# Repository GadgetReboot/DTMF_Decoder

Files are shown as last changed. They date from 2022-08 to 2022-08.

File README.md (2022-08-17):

# DTMF_Decoder
MT8870 DTMF decoder for POTS phone line interfacing <BR>
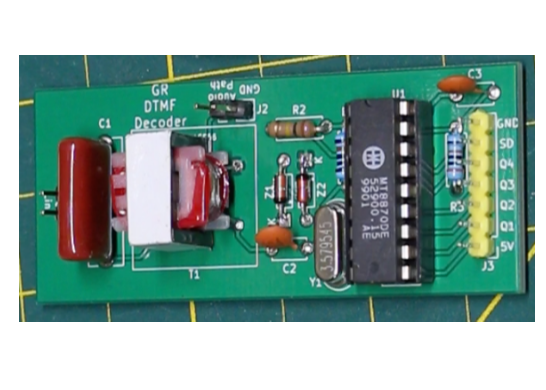
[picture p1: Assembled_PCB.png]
pcb
<br>
This pcb allows connecting across a phone line tip and ring and when DTMF signals are present, they are decoded into 4 bit data with a data ready signal.<br>
An Arduino can then detect DTMF touch tones present on a phone line.<br>
Note: It is recommended to only connect this circuit to a phone line after it is taken off hook to keep the AC voltages low, such as audio signals and not a high voltage ring signal.<br>
This can be achieved by switching the circuit into the phone line with a relay.<br><br>
This circuit has only been tested on a simulated phone line in a workshop environment and is not guaranteed to meet official telephone line specifications.

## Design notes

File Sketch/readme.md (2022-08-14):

DTMF decoder example that prints out the decoded phone key press on the serial monitor

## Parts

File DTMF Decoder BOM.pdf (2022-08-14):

DTMF Decoder BOM

Qty | References | Description
2 | C2 C3 | Capacitor 100nF >=10V 5mm pitch
1 | C1 | Capacitor 0.56uF 250V 15mm pitch
2 | J1 J2 | Header 2.54mm 2 pin
1 | J3 | Header 2.54mm 7 pin
2 | R1 R2 | Resistor 100K 1/4 watt through hole
1 | R3 | Resistor 300K 1/4 watt through hole
1 | T1 | 600:600 Transformer eg. model EI14 on AliExpress
1 | U1 | MT8870DE DIP18
1 | Y1 | 3.579545 MHz HC49/4H
2 | Z1 Z2 | Zener Diode 3V3 1N746A DO-35

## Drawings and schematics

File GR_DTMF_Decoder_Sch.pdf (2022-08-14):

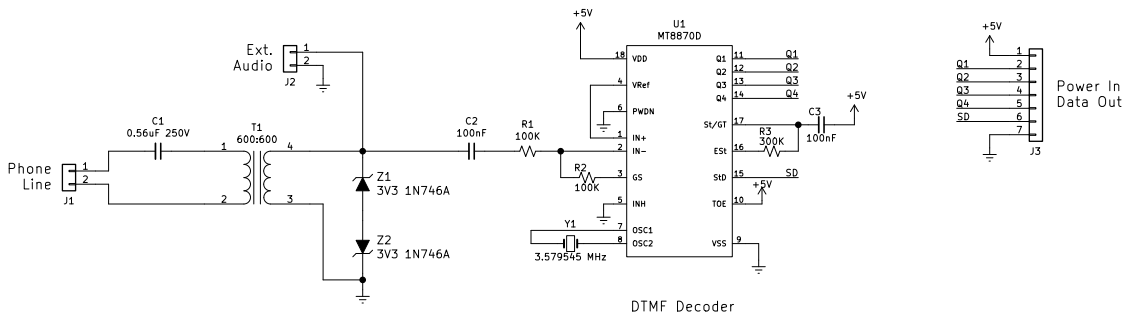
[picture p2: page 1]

https://github.com/GadgetReboot/DTMF_Decoder
https://www.youtube.com/gadgetreboot
File: GR_DTMF_Decoder.sch Sheet: / Gadget Reboot

Id: 1/1 Title: DTMF Decoder

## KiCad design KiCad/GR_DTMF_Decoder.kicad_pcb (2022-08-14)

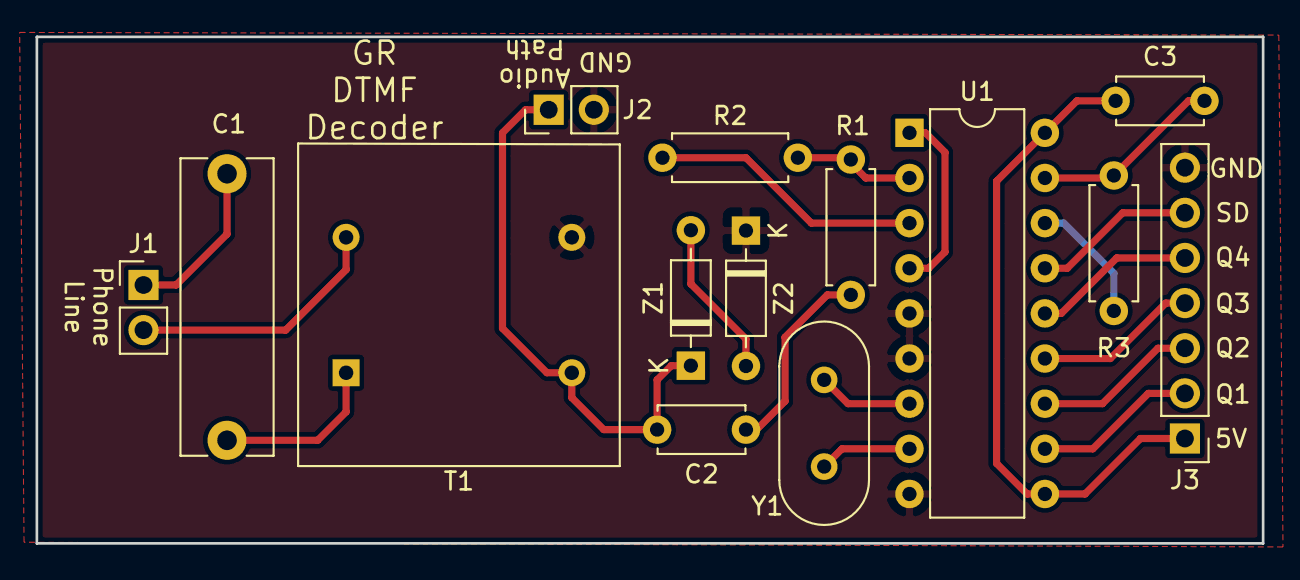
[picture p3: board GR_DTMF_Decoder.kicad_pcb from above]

Board: 2 copper layers, 69.0 x 28.5 mm, 14 parts (0 on the bottom side), 20 nets.

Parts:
C1: 0.56uF 250V; C_Rect_L16.5mm_W5.0mm_P15.00mm_MKT
C2, C3: 100nF; C_Disc_D4.7mm_W2.5mm_P5.00mm
J1, J2: Conn_01x02; PinHeader_1x02_P2.54mm_Vertical
J3: Conn_01x07; PinHeader_1x07_P2.54mm_Vertical
R1, R2: 100K; R_Axial_DIN0207_L6.3mm_D2.5mm_P7.62mm_Horizontal
R3: 300K; R_Axial_DIN0207_L6.3mm_D2.5mm_P7.62mm_Horizontal
T1: 600:600; Transformer_NF_ETAL_P3324
U1: MT8870D; DIP-18_W7.62mm
Y1: 3.579545 MHz; Crystal_HC49-4H_Vertical
Z1, Z2: 3V3; D_DO-35_SOD27_P7.62mm_Horizontal

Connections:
+5V: C3.1, J3.1, U1.10, U1.18
/Q1: J3.2, U1.11
/Q2: J3.3, U1.12
/Q3: J3.4, U1.13
/Q4: J3.5, U1.14
/SD: J3.6, U1.15
GNDREF: J2.2, J3.7, T1.3, U1.5, U1.6, U1.9, Z2.K
unnamed: C1.1, T1.1
unnamed: C1.2, J1.1
unnamed: C2.1, R1.2
unnamed: C2.2, J2.1, T1.4, Z1.K
unnamed: C3.2, R3.1, U1.17
unnamed: J1.2, T1.2
unnamed: R1.1, R2.2, U1.2
unnamed: R2.1, U1.3
unnamed: R3.2, U1.16
unnamed: U1.1, U1.4
unnamed: U1.7, Y1.1
unnamed: U1.8, Y1.2
unnamed: Z1.A, Z2.A

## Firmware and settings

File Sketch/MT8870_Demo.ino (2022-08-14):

// MT8870 DTMF Decoder Demo
// Target Hardware:  Uno
//
// MT8870 Pin         Uno Pin
//   Q1                  2
//   Q2                  3
//   Q3                  4
//   Q4                  5
//   StD                 6
//
// Tested with Arduino IDE 1.8.13
// Gadget Reboot
// https://www.youtube.com/gadgetreboot

// input pins from MT8870
const byte Q1 = 2;
const byte Q2 = 3;
const byte Q3 = 4;
const byte Q4 = 5;
const byte StD = 6;

void setup() {
  Serial.begin(9600);

  pinMode(Q1, INPUT);
  pinMode(Q2, INPUT);
  pinMode(Q3, INPUT);
  pinMode(Q4, INPUT);
  pinMode(StD, INPUT);
}

void loop() {

  // StD (delayed steering) output from MT8870 is high while a DTMF signal is present, low when not
  // when a DTMF tone pair is present, decode the key pressed (0-9, *, #)  A, B, C, D  are not decoded
  if (digitalRead(StD)) {
    uint8_t dtmf = ( 0x00 | (digitalRead(Q1) << 0) | (digitalRead(Q2) << 1) | (digitalRead(Q3) << 2) | (digitalRead(Q4) << 3) );
    switch (dtmf)
    {
      case 0x01:
        Serial.println("DTMF: 1");
        break;
      case 0x02:
        Serial.println("DTMF: 2");
        break;
      case 0x03:
        Serial.println("DTMF: 3");
        break;
      case 0x04:
        Serial.println("DTMF: 4");
        break;
      case 0x05:
        Serial.println("DTMF: 5");
        break;
      case 0x06:
        Serial.println("DTMF: 6");
        break;
      case 0x07:
        Serial.println("DTMF: 7");
        break;
      case 0x08:
        Serial.println("DTMF: 8");
        break;
      case 0x09:
        Serial.println("DTMF: 9");
        break;
      case 0x0A:
        Serial.println("DTMF: 0");
        break;
      case 0x0B:
        Serial.println("DTMF: *");
        break;
      case 0x0C:
        Serial.println("DTMF: #");
        break;
    }
    while (digitalRead(StD)) {};  // wait for current dtmf signal to end before looking for the next one
  }
}
